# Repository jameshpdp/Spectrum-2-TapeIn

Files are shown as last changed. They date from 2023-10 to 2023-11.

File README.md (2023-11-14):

# ZX Spectrum +2 (Grey) External Tape Input PCB

This is a simple PCB layout for building circuit designed by
[JoulesperCoulomb](https://youtu.be/qUIv-A_DOc0?t=1213), please
watch the video for all the details.

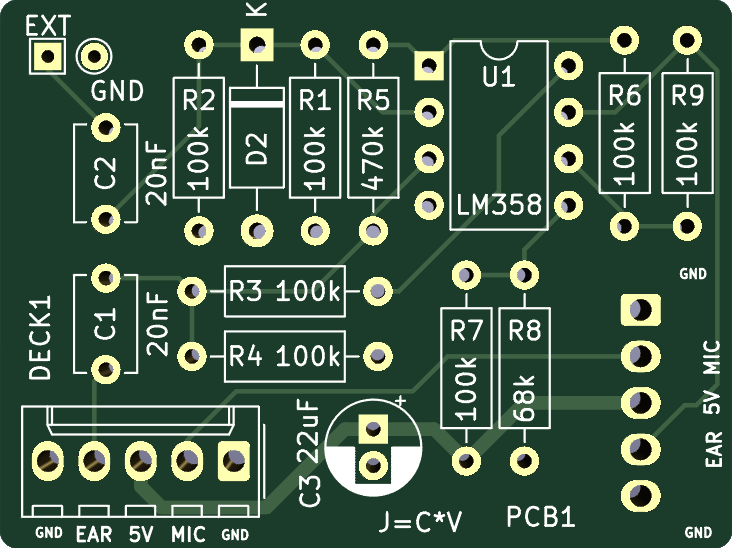
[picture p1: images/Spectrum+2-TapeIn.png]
PCB


Board size 40mm x 30mm. Gerber files under `export/`, original KiCad project under
`Spectrum+2-TapeIn.KiCad/`.

## Building

Building this circuit shold be straghtforward with one exception. It is recommended to solder wires directly to the PCB1 pads and avoid using pin header there.

NOTE: While PCB1 connector footprint allows for soldering KK 254 / KF 2510  pin header, great care should be taken to solder those correctly. The problem is not the pin header itself, but the cable you need to use to connect it to the main board. Most pre-crimped cables available at the time of writing (2023) are the cross-wired ones (pin 1 to 5, pin 2 to 4, pin 4 to 2, pin 5 to 1). Which means if you do not pay attention you may end up cross-connecting MIC and EAR. At best, nothing will work. At worst, you may damage that precious ULA. Just get the wires with the KK 254 / KF 2510 connector on one end and carefully solder wires according to the skilscreen markings.

[Interactive BOM](https://htmlpreview.github.io/?https://github.com/jameshpdp/Spectrum-2-TapeIn/blob/main/bom/ibom.html)

| Reference | Item | Count |
| --- | --- | ----- |
| C1, C2 | 20 nF | 2 |
| C3 | 22 uF | 1 |
| R1-R4, R6, R7, R9 | 100 kOhm | 7 |
| R5 | 470 kOhm | 1 |
| R8 | 68 kOhm  | 1 |
| D2 | 1N5819 | 1 |
| U1 | LM358 | 1 |
| DECK1, PCB1 (opt) | Molex KK-254 AE-6410 | 1 (2) |

Molex KK 254 / KF 2510 connectors optional, required only if you want to avoid cutting/modifing existing tape deck wiring. Otherwise you can simply solder wires to the corresponding pads as marked on the PCB.

## Revision Hisory
Rev. C -- first public release

Rev. D -- KK 254 / 2510 connectors (optional), removed D1, extra details on the silkscreen

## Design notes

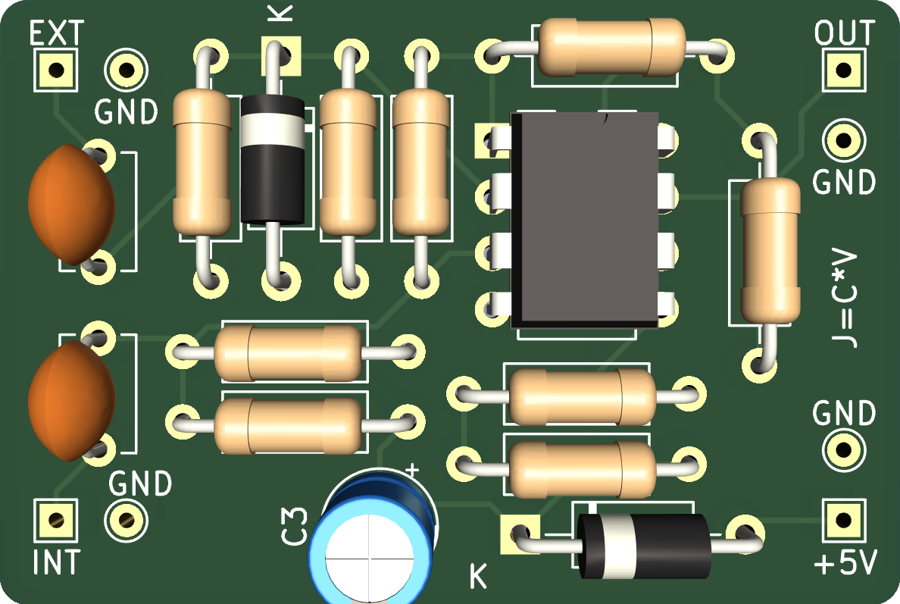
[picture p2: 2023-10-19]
images/rev-c/Spectrum+2-TapeIn.c.png

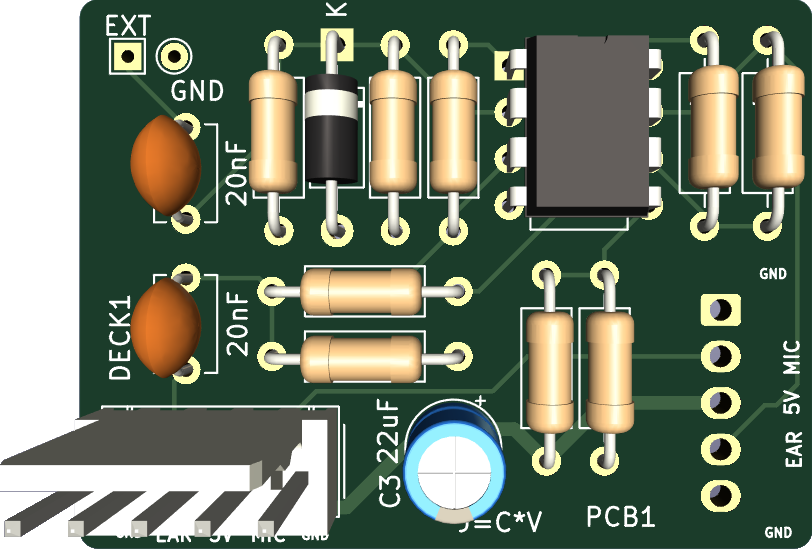
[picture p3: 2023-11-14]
images/Spectrum+2-TapeIn.c.png

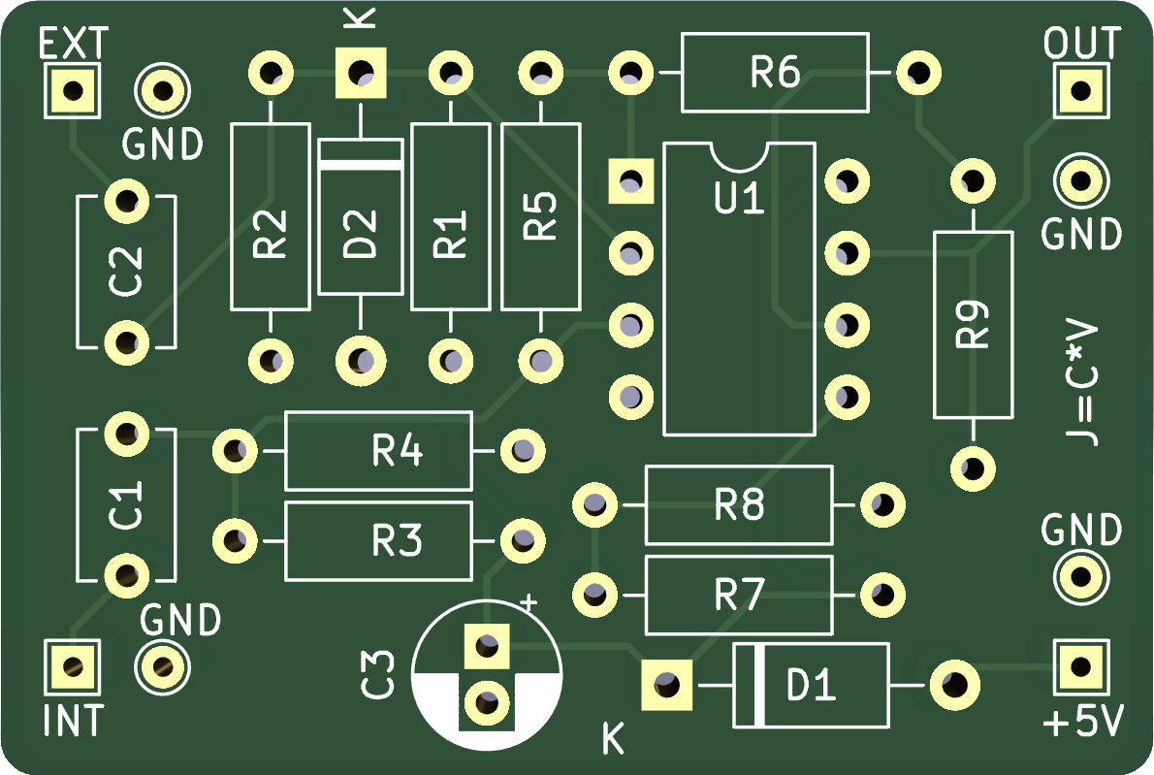
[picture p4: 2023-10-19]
images/rev-c/Spectrum+2-TapeIn.png

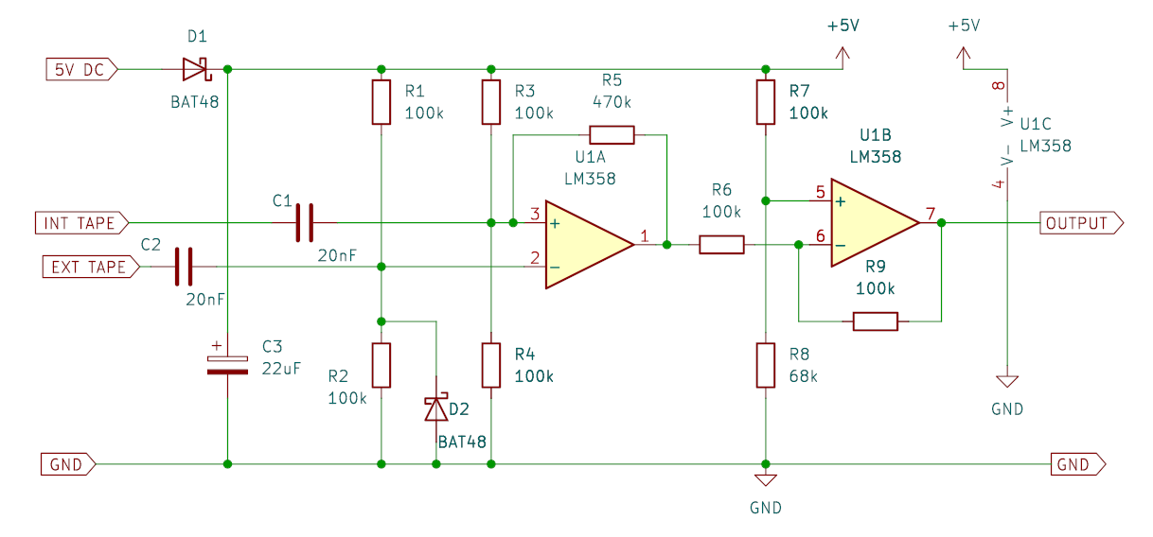
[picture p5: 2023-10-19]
export/Spectrum+2-TapeIn.png

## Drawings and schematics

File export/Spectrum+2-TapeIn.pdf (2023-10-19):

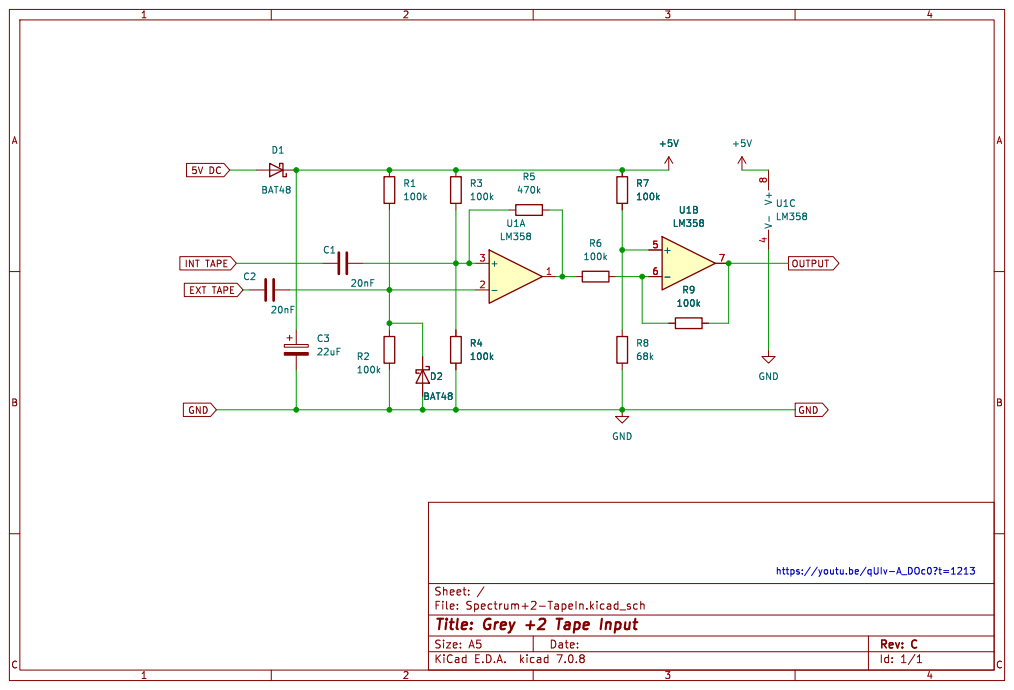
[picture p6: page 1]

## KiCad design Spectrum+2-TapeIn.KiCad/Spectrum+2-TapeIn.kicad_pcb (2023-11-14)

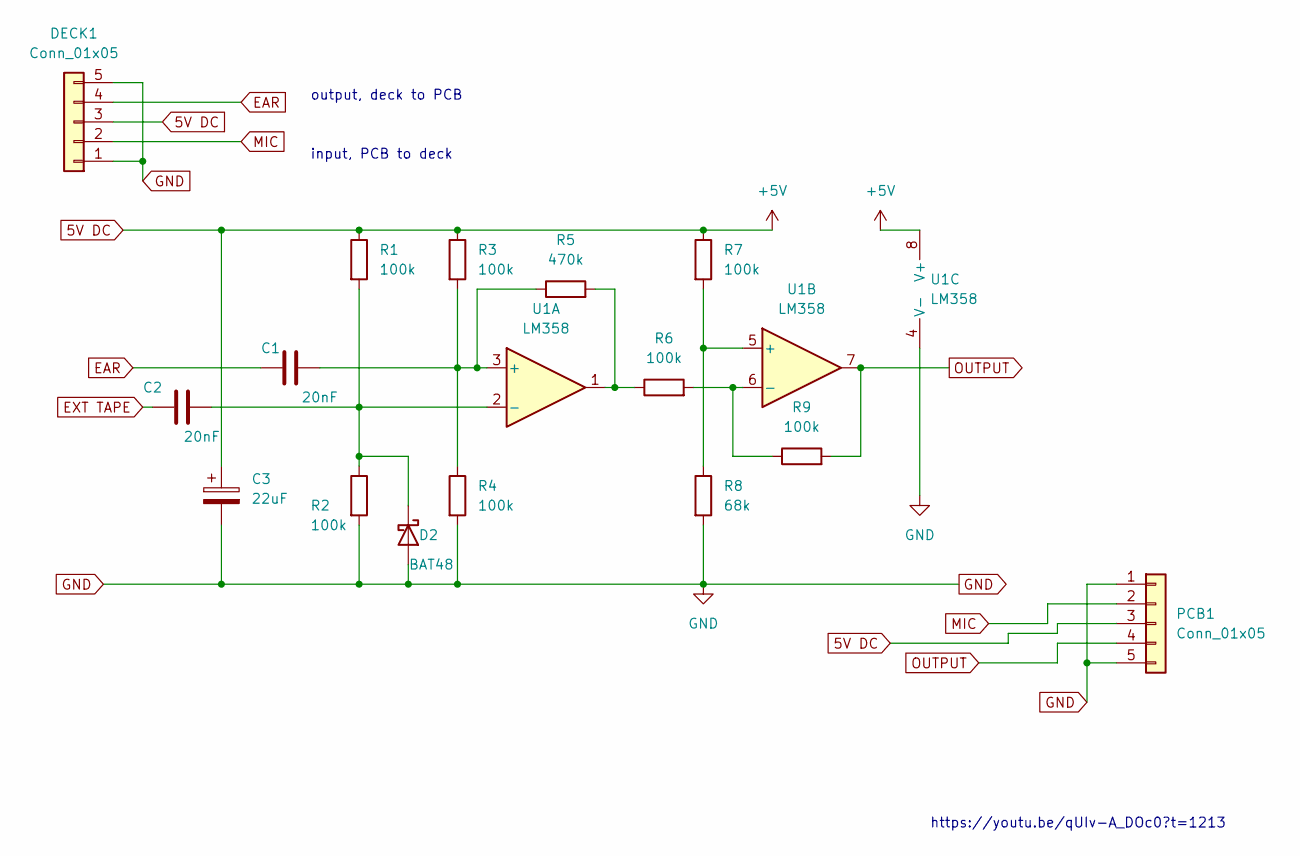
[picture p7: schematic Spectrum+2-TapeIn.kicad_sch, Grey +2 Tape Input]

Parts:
C1, C2: 20nF; C_Disc_D5.1mm_W3.2mm_P5.00mm; Part Number K223K15X7RF53L2
C3: 22uF; CP_Radial_D5.0mm_P2.00mm; Part Number ECA1CM220
D2: BAT48; D_A-405_P10.16mm_Horizontal; Part Number BAT48RL
DECK1: Conn_01x05; Molex_KK-254_AE-6410-05A_1x05_P2.54mm_Vertical
PCB1: Conn_01x05; Molex_KK-254_AE-6410-06A_1x05_P2.54mm_Vertical
R1, R2, R3, R4, R6, R7, R9: 100k; R_Axial_DIN0207_L6.3mm_D2.5mm_P10.16mm_Horizontal; Part Number 100k 0.25W
R5: 470k; R_Axial_DIN0207_L6.3mm_D2.5mm_P10.16mm_Horizontal; Part Number 470k 0.25W
R8: 68k; R_Axial_DIN0207_L6.3mm_D2.5mm_P10.16mm_Horizontal; Part Number 68k 0.25W
U1: LM358; DIP-8_W7.62mm; Part Number LM358

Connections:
5V DC: C3.1, DECK1.3, PCB1.3, R1.1, R3.1, R7.1, U1.8 (V+)
EAR: C1.1, DECK1.4
EXT TAPE: C2.1; also elsewhere on the board
GND: C3.2, D2.2 (A), DECK1.1, DECK1.5, PCB1.1, PCB1.5, R2.2, R4.2, R8.2, U1.4 (V-); also elsewhere on the board
MIC: DECK1.2, PCB1.2
unnamed: C2.2, D2.1 (K), R1.2, R2.1, U1.2 (-)
unnamed: R5.2, R6.1, U1.1
unnamed: C1.2, R3.2, R4.1, R5.1, U1.3 (+)
unnamed: R7.2, R8.1, U1.5 (+)
unnamed: R6.2, R9.1, U1.6 (-)
OUTPUT: PCB1.4, R9.2, U1.7

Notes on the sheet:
input, PCB to deck
output, deck to PCB
https://youtu.be/qUIv-A_DOc0?t=1213

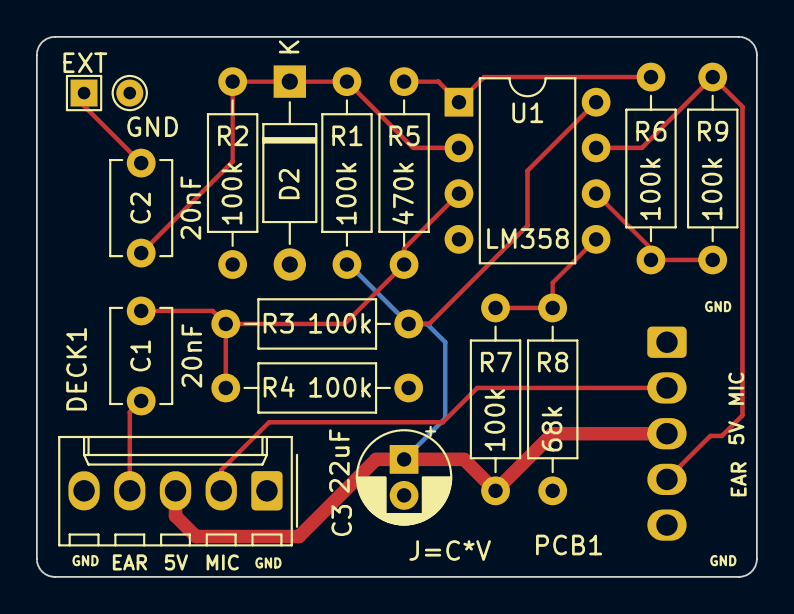
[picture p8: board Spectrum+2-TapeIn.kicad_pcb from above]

Board: 2 copper layers, 40.0 x 30.0 mm, 18 parts (0 on the bottom side), 11 nets.

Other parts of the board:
EXT: TestPoint_THTPad_1.5x1.5mm_Drill0.7mm
GND: TestPoint_THTPad_D1.5mm_Drill0.7mm

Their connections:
EXT TAPE: EXT.1; also elsewhere on the board
GND: GND.1; also elsewhere on the board

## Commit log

2023-10-19 Initial import
    [Spectrum+2-TapeIn.kicad_pcb, Spectrum+2-TapeIn.kicad_sch]
2023-11-14 Rev. D
    Proper connector for deck plug (no need to cut the wires).
    Improved silkscreen, makes it easier to place components when building.
    [Spectrum+2-TapeIn.kicad_pcb, Spectrum+2-TapeIn.kicad_sch]
2023-11-14 Typo, preview link.
    Typo, pin does not respond to a ping :) Preview link for BOM page.
